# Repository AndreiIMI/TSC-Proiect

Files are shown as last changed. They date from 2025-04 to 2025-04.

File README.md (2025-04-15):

# TSC-Proiect
## Schema Bloc
SchemaBloc
## BOM (Bill of Materials)
| Component | Link | Datasheet |
|---|---|---|
| ESP32-C6-WROOM-1-N8 | [Link](https://ro.mouser.com/ProductDetail/Espressif-Systems/ESP32-C6-WROOM-1-N8?qs=8Wlm6%252BaMh8ST02Gmwp74cw%3D%3D) | [Datasheet](https://ro.mouser.com/datasheet/2/891/Espressif_ESP32_C6_WROOM_1__Datasheet_V0_1_PRELIMI-3239987.pdf) |
| 112A-TAAR-R03_ATTEND | [Link](https://www.digikey.ro/ro/products/detail/attend-technology/112A-TAAR-R03/17633923) | [Datasheet](https://www.attend.com.tw/data/download/file/112A-TAAR-R03_Spec.pdf) |
| ADAFRUIT_LEDCHIP-LED0603 | [Link](https://www.snapeda.com/parts/KP-1608SURCK/Kingbright/view-part/?ref=search&t=LED%200603) | [Datasheet](https://www.snapeda.com/parts/KP-1608SURCK/Kingbright/datasheet/) |
| ESP32_WROVER_EAGLE-LTSPICE_RR0402 | [Link](https://www.snapeda.com/parts/RC0402FR-07226RL/Yageo/view-part/) | [Datasheet](https://www.snapeda.com/parts/RC0402FR-07226RL/Yageo/datasheet/) |
| ESP32_WROVER_EAGLE-LTSPICE_CC0402 | [Link](https://componentsearchengine.com/part-view/CC0402MRX5R5BB106/YAGEO) | [Datasheet](https://componentsearchengine.com/Datasheets/2/CC0402MRX5R5BB106.pdf) |
| RCL_CPOL-EUCT3528 | [Link](https://ro.mouser.com/ProductDetail/Vishay-Sprague/TR3B106K025C1300?qs=jCGqFXxTmLdffnuDkXzk1g%3D%3D) | [Datasheet](https://www.vishay.com/docs/40080/tr3.pdf) |
| ESP32_WROVER_SPARKFUN-DISCRETESEMI_MOSFET_PCH-DMG2305UX-7 | [Link](https://ro.mouser.com/ProductDetail/Diodes-Incorporated/DMG2305UX-7?qs=L1DZKBg7t5F%2FNBHrjfxC%252Bg%3D%3D) | [Datasheet](https://www.diodes.com/assets/Datasheets/DMG2305UX.pdf) |
| 744043680IND_4828-WE-TPC_WRE | [Link](https://www.digikey.sg/en/products/detail/w%C3%BCrth-elektronik/744043680/1638515) | [Datasheet](https://www.we-online.com/components/products/datasheet/744043680.pdf) |
| BD5229G-TR | [Link](https://ro.mouser.com/ProductDetail/ROHM-Semiconductor/BD5229G-TR?qs=4kLU8WoGk0vvnhrrYwdszw%3D%3D) | [Datasheet](https://fscdn.rohm.com/en/products/databook/datasheet/ic/power/voltage_detector/bd52xxg-e.pdf) |
| ESP32_WROVER_BME680_BME680 | [Link](https://ro.mouser.com/ProductDetail/Bosch-Sensortec/BME680?qs=v271MhAjFHjo0yA%2FC4OnDQ%3D%3D) | [Datasheet](https://ro.mouser.com/datasheet/2/783/BST_BME680_DS001-1509608.pdf) |
| BUTTON_CUSTOMV1 | [Link](https://ro.mouser.com/ProductDetail/Panasonic/EVQ-P7M01P?qs=rJ%252BziJWpysz0sJAzuCybtw%3D%3D) | [Datasheet](https://industry.panasonic.com/global/en/downloads/?file_cd=402906&tab=catalog&series_cd=3457) |
| CPH3225A | [Link](https://ro.mouser.com/ProductDetail/Seiko-Semiconductors/CPH3225A?qs=3etwrb1wR%252BhUOph6lAO7eg%3D%3D) | [Datasheet](https://ro.mouser.com/datasheet/2/360/Seiko_Instruments_MicroBattery_E_20230330_2024Jan_-3561061.pdf) |
| DS3231SN# | [Link](https://ro.mouser.com/ProductDetail/Analog-Devices-Maxim-Integrated/DS3231SN?qs=1eQvB6Dk1vhUlr8%2FOrV0Fw%3D%3D) | [Datasheet](https://ro.mouser.com/datasheet/2/609/DS3231-3421123.pdf) |
| ESP32C6_VARISTORCN1812 | [Link](https://eu.mouser.com/ProductDetail/KEMET/VC1812L501R008?qs=jj7GbYRQuOa1j1%2F3gPpdvQ%3D%3D) | [Datasheet](https://eu.mouser.com/datasheet/2/447/KEM_V0002_VC-3316862.pdf) |
| ESP32_WROVER_AVX---SD0805S020S1R0_AVX_SD0805S020S1R0_0_0AVX_SD0805S020S1R0_0_0 | [Link](https://eu.mouser.com/ProductDetail/KYOCERA-AVX/SD0805S020S1R0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) | [Datasheet](https://eu.mouser.com/datasheet/2/40/schottky-3165252.pdf) |
| FH34SRJ-24S-0.5SH_99_ | [Link](https://eu.mouser.com/ProductDetail/Hirose-Connector/FH34SRJ-24S-05SH99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) | [Datasheet](https://eu.mouser.com/datasheet/2/185/FH34SRJ_24S_0_5SH_99__CL0580_1255_6_99_2DDrawing_0-1615044.pdf) |
| MAX17048G+T10 | [Link](https://eu.mouser.com/ProductDetail/Analog-Devices-Maxim-Integrated/MAX17048G+T10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) | [Datasheet](https://eu.mouser.com/datasheet/2/609/MAX17048_MAX17049-3469099.pdf) |
| MBR0530 | [Link](https://eu.mouser.com/ProductDetail/Micro-Commercial-Components-MCC/MBR0530-TP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) | [Datasheet](https://eu.mouser.com/datasheet/2/258/MBR0520_MBR0580_SOD123_-2492194.pdf) |
| ESP32_WROVER_SPARKFUN-IC-POWER_MCP73831 | [Link](https://ro.mouser.com/ProductDetail/Microchip-Technology/MCP73831-2DCI-MC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) | [Datasheet](https://ro.mouser.com/datasheet/2/268/MCP73831_Family_Data_Sheet_DS20001984H-3441711.pdf) |
| PGB1010603MR | [Link](https://ro.mouser.com/ProductDetail/Littelfuse/PGB1010603MR?qs=gu7KAQ731URLg4GSnNNN7Q%3D%3D) | [Datasheet](https://www.littelfuse.com/assetdocs/pulseguard-esd-suppressors-pgb1-datasheet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) |
| QWIIC_CONNECTORJS-1MM | [Link](https://www.sparkfun.com/qwiic-jst-connector-smd-4-pin-vertical.html) | [Datasheet](https://www.jst-mfg.com/product/pdf/eng/eSH.pdf?5ec58813d214e) |
| SAMACSYS_PARTS_USB4110-GF-A | [Link](https://eu.mouser.com/ProductDetail/GCT/USB4110-GF-A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) | [Datasheet](https://eu.mouser.com/datasheet/2/837/GCT_USB4110_Product_Drawing___20k_cycles-3455479.pdf) |
| SI1308EDL-T1-GE3 | [Link](https://eu.mouser.com/ProductDetail/Vishay-Semiconductors/SI1308EDL-T1-GE3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) | [Datasheet](https://www.vishay.com/docs/63399/si1308edl.pdf) |
| USBLC6-2SC6Y | [Link](https://eu.mouser.com/ProductDetail/STMicroelectronics/USBLC6-2SC6Y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) | [Datasheet](https://eu.mouser.com/datasheet/2/389/usblc6_2sc6y-1852505.pdf) |
| SJ | [Link](https://grabcad.com/library/solder-jumpers-1) | [Datasheet](https://github.com/cristiandeda/TSC_E-BookReader/blob/main) |
| W25Q512JVEIQ | [Link](https://eu.mouser.com/ProductDetail/Winbond/W25Q512JVEIQ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) | [Datasheet](https://eu.mouser.com/datasheet/2/949/Winbond_W25Q512JV_Datasheet-3240039.pdf) |
| XC6220A331MR-G | [Link](https://eu.mouser.com/ProductDetail/Torex-Semiconductor/XC6220A331MR-G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) | [Datasheet](https://eu.mouser.com/datasheet/2/760/xc6220-3371556.pdf) |
## Descrierea funcționalității hardware
Această placă integrează multiple componente pentru a oferi o soluție completă de control, senzorizare și afișare cu consum redus, ideală pentru aplicații IoT.

### Alimentare și Încărcare
* #### Conector USB-C
  Oferă atât alimentare principală (5V), cât și comunicație de date.

* #### Regulator tensiune (IC1)
  Convertor step-down care aduce tensiunea de la 5V la 3.3V, necesară pentru alimentarea ESP32 și a celorlalte circuite logice.

* #### Protecție la supratensiuni (TVS - D1, PFMF.050.1)
  Diodă TVS care protejează linia de alimentare USB și comunicație împotriva descărcărilor electrostatice (ESD) și supratensiunilor.

* #### Control încărcare baterie (MCP73831)
  Circuit dedicat pentru încărcarea bateriilor Li-Po, cu protecție la supraîncărcare și descărcare. Condensatorii C1 și C2 filtrează zgomotul de pe linia de alimentare.

* #### Monitorizare baterie (MAX17048)
  Cititor de nivel al bateriei cu comunicație I2C, oferă date precise despre starea acumulatorului în timp real.

### Memorie și Stocare
* #### Memorie NOR Flash SPI (W25Q512JVEIQ)
  Stocare de 64MB pentru fișiere (imagini, texte, baze de date), conectată la ESP32 prin SPI.

* #### Cititor card SD
  Conectat pe interfață SPI (IO8–IO11), permite extinderea capacității de stocare, ideal pentru loguri sau import de fișiere externe.

### Control Principal - ESP32-C6
* #### Microcontroller ESP32-C6-WROOM-1-N8
  Nucleul principal al plăcii, gestionează toate perifericele. Suportă Wi-Fi 6, BLE 5.2, Zigbee și Thread. Dispune de GPIO-uri versatile pentru SPI, I2C, UART și control direct pentru afișajele e-paper.

### Ceas în Timp Real (RTC)
* #### DS3231SN
  Modul de ceas cu precizie ridicată, conectat prin I2C. Are o baterie de rezervă ce menține ora actualizată chiar și fără alimentare principală.

### Senzor Ambiental
* #### BME688
  Senzor avansat care măsoară temperatura, umiditatea, presiunea atmosferică și calitatea aerului. Comunicarea se face prin I2C.

### Afișaj E-Paper
* #### Header dedicat pentru E-Ink Display
  Permite conectarea unui afișaj e-paper cu consum ultra-redus.

* #### Circuit de control semnal (MBR0530, L1, Q3)
  Asigură comutarea corectă a tensiunii și semnalelor pentru afișaj.

* #### Selectare ecran
  Prin jumperul S1 se poate selecta tipul de e-paper utilizat.

### Interfețe Extinse
* #### Qwiic / Stemma QT
  Conector standard JST-SH cu 4 pini pentru adăugarea de senzori sau module I2C externe cu plug-and-play.

* #### Test Pads GPIO
  Paduri expuse pentru pini importanți ai ESP32. Ușurează depanarea, măsurătorile sau conectarea de periferice suplimentare.

### Protecție și Control
* #### Protecție ESD pe SPI & Qwiic
  Include diode TVS și rezistențe pentru protecția semnalelor împotriva descărcărilor electrostatice.

* #### Butoane de control (RESET & BOOT)
  RESET – repornește sistemul; BOOT – folosit pentru programarea ESP32. Ambele conectate la pini esențiali (EN și IO0).

## Descrierea Pinilor ESP32-C6

| **Pin ESP32-C6** | **Nume Semnal** | **Componentă Asociată** | **Scop / Funcție** |
|---|---|---|---|
| **GND** | GND | Toate componentele | Masă comună pentru alimentare și semnal. |
| **EN** | Enable | Buton Reset | Resetează microcontrollerul la apăsare. |
| **IO0** | GPIO0 | Buton BOOT | Intrare în modul de boot la apăsare. |

### Test & GPIO General

| **Pin ESP32-C6** | **Nume Semnal** | **Componentă Asociată** | **Scop / Funcție** |
|---|---|---|---|
| **IO1** | GPIO1 | Test Pad TP11 | I/O general sau pentru debug. |
| **IO2** | GPIO2 | Test Pad TP12 | I/O general sau pentru debug. |
| **IO3** | GPIO3 | Test Pad TP13 | I/O general sau pentru debug. |

### Memorie NOR Flash (SPI)

| **Pin ESP32-C6** | **Nume Semnal** | **Componentă Asociată** | **Scop / Funcție** |
|---|---|---|---|
| **IO4** | CS | SPI Flash (W25Q512JVEIQ) | Chip Select pentru memoria externă. |
| **IO5** | CLK | SPI Flash | Clock SPI pentru NOR Flash. |
| **IO6** | MISO | SPI Flash | Date din NOR Flash către ESP32. |
| **IO7** | MOSI | SPI Flash | Date de la ESP32 către NOR Flash. |

### Card SD (SPI)

| **Pin ESP32-C6** | **Nume Semnal** | **Componentă Asociată** | **Scop / Funcție** |
|---|---|---|---|
| **IO8** | CS | SD Card | Chip Select pentru card SD. |
| **IO9** | CLK | SD Card | Clock SPI pentru card SD. |
| **IO10** | MISO | SD Card | Date de pe card SD către ESP32. |
| **IO11** | MOSI | SD Card | Date de la ESP32 către card SD. |

### E-Paper Display

| **Pin ESP32-C6** | **Nume Semnal** | **Componentă Asociată** | **Scop / Funcție** |
|---|---|---|---|
| **IO12** | BUSY / RST / etc. | E-Paper Header | Semnale de control pentru afișaj. |
| **IO13** | - | E-Paper Header | Semnal suplimentar pentru afișaj. |
| **IO14** | - | E-Paper Header | Semnal suplimentar pentru afișaj. |
| **IO15** | - | E-Paper Header | Semnal suplimentar pentru afișaj. |

### Magistrală I2C (RTC & Senzor Mediu)

| **Pin ESP32-C6** | **Nume Semnal** | **Componentă Asociată** | **Scop / Funcție** |
|---|---|---|---|
| **IO16** | SCL | RTC (DS3231), BME688 | Clock pentru comunicația I2C. |
| **IO17** | SDA | RTC (DS3231), BME688 | Date pentru comunicația I2C. |

### Serial Debug / Qwiic

| **Pin ESP32-C6** | **Nume Semnal** | **Componentă Asociată** | **Scop / Funcție** |
|---|---|---|---|
| **IO18** | UART_RX | Qwiic / Debug Header | Recepție serială (ex: debugging, interfață Qwiic). |
| **IO19** | UART_TX | Qwiic / Debug Header | Transmisie serială. |

## Pași de Implementare

1. **Proiectarea Schemei**
   - Am realizat schema electrică folosind componente din biblioteca specificată.
   - Am verificat schema cu ERC și am rezolvat toate erorile relevante.
   - M-am asigurat că toate componentele au footprint corect și conexiuni valide.

2. **Plasarea Componentelor pe PCB**
   - Am plasat toate componentele exclusiv pe layer-ul **TOP**, conform cerințelor.
   - Am amplasat corect condensatoarele de decuplare (100nF) lângă pinii de alimentare.
   - Am poziționat antena modulului ESP32 spre exteriorul plăcii și am decupat zona de sub ea.
   - Am ignorat erorile de dimension generate de butoane și mufa USB, conform instrucțiunilor.

3. **Rutarea PCB-ului**
   - Am rutat traseele de alimentare cu **width = 0.3mm** și cele de semnal cu **minim 0.15mm**.
   - Am evitat unghiurile drepte și am minimizat utilizarea de vias-uri pe traseele de putere.
   - Fiind o placă dublu strat, am aplicat **via stitching** între planurile de masă.
   - Nu am rutat trasee sub antena ESP32 și am decupat zona PCB-ului din acea regiune.

4. **Verificare și Validare**
   - Am folosit fișierul de verificare pentru DRC și am corectat toate problemele importante.
   - Am ignorat eroarea “Only INPUT pins on NET ID” conform indicațiilor.
   - Am marcat clar toate test pad-urile în silkscreen cu denumirile semnalelor (ex. MOSI, RX).

5. **Realizarea Silkscreen-ului**
   - Am păstrat silkscreen-ul clar și lizibil, cu **numele componentelor**, fără valorile acestora.

6. **Modelarea 3D**
   - Am importat modelul 3D al PCB-ului în carcasa furnizată.
   - Am desenat bateria și ecranul conform dimensiunilor mecanice din datasheet-uri.

7. **Generarea Fișierelor Finale**
   - Am generat fișierele **Gerber** conform tutorialului oferit.
   - Am creat fișierele **BOM** și **Pick and Place** pentru fabricație, urmând pașii din tutorial.
   - Pentru componente și modele 3D, am folosit [Component Search Engine](https://componentsearchengine.com).

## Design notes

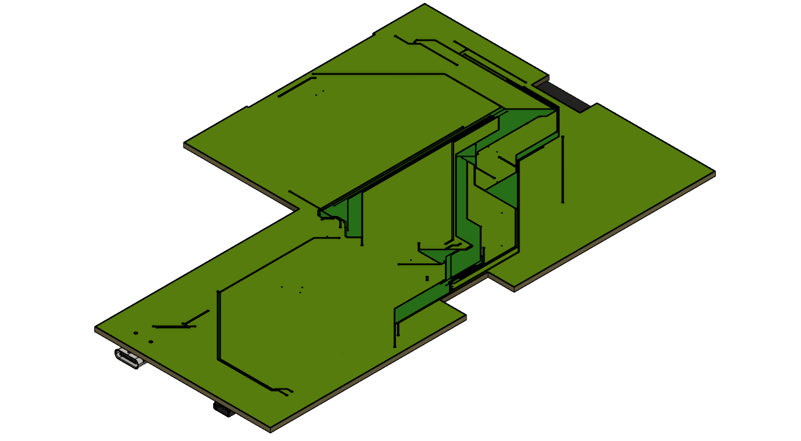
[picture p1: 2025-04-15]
Images/PCB Bottom.png

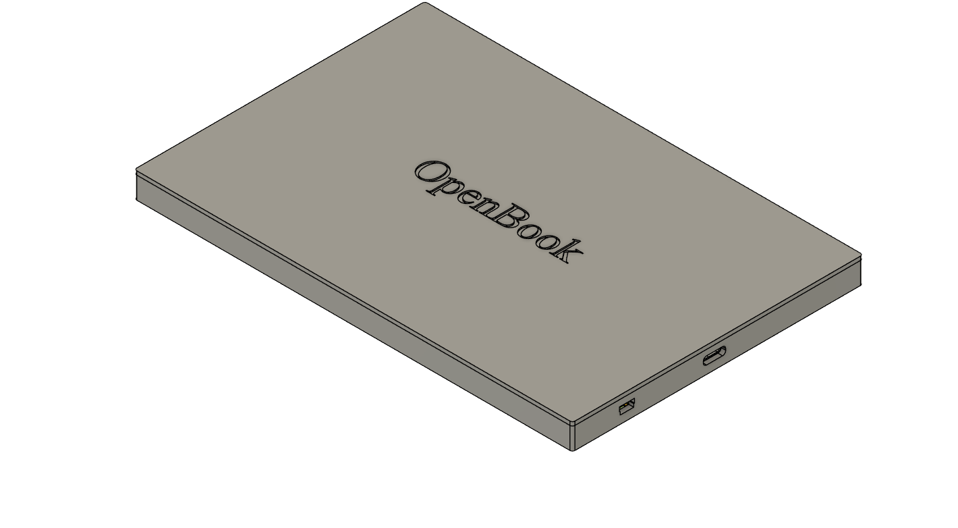
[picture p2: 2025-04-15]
Images/OpenBook_Model-Full v2.png

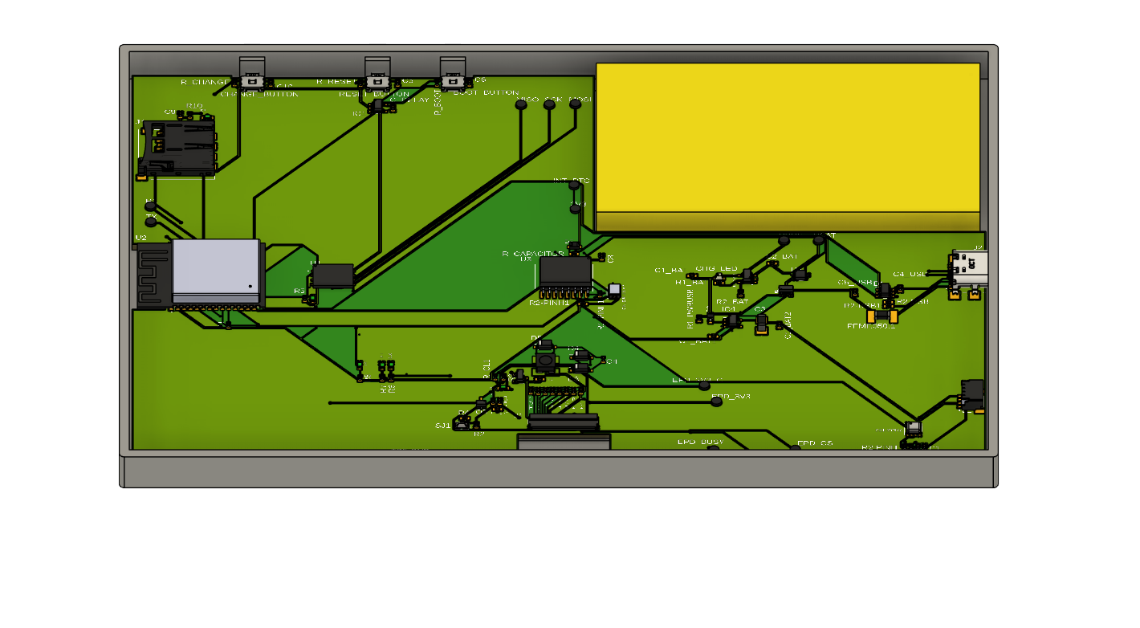
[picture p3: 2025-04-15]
Images/OpenBook_Model-Full Open.png

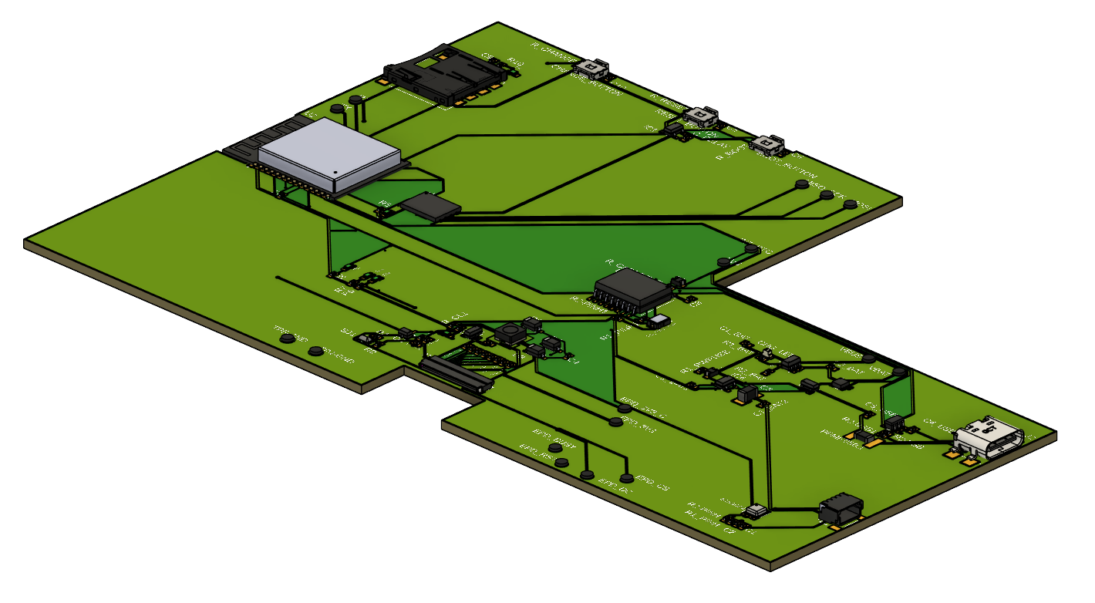
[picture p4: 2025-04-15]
Images/PCB.png

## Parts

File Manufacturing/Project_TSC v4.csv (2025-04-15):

Qty | Value | Device | Package | Parts | Description | ARROW_PART_NUMBER | ARROW_PRICE-STOCK | AVAILABILITY | CENTROID_NOT_SPECIFIED | CHECK_PRICES | COPYRIGHT | DATASHEET | DESCRIPTION | DIGIKEY_DESCRIPTION | DIGIKEY_PART_NUMBER | HEIGHT | LEAD_FREE | MANUFACTURER_NAME | MANUFACTURER_PART_NUMBER | MF | MFR_NAME | MOUSER_PART_NUMBER | MOUSER_PRICE-STOCK | MOUSER_TESTING_PART_NUMBER | MOUSER_TESTING_PRICE-STOCK | MP | MPN | PACKAGE | POPULARITY | PREFIX | PRICE | PROD_ID | PURCHASE-URL | ROHS | SNAPEDA_LINK | SPICEMODEL | SPICEPREFIX | TEMPERATURE_RANGE_HIGH | TEMPERATURE_RANGE_LOW | TP_SIGNAL_NAME | VALUE
1 |  | ADAFRUIT_LEDCHIP-LED0603 | ADAFRUIT_CHIP-LED0603 | CHG_LED | LED
1 |  | SJ | SJ | SJ1 | SMD solder JUMPER |  |  |  |  |  |  |  |  |  |  |  |  |  |  |  |  |  |  |  |  |  |  |  | 3
1 | 0.47 | ESP32_WROVER_EAGLE-LTSPICE_RR0402 | ESP32_WROVER_EAGLE-LTSPICE_R0402 | R3 | RESISTOR, European symbol |  |  |  |  |  |  |  |  |  |  |  |  |  |  |  |  |  |  |  |  |  |  |  |  |  |  |  |  |  |  | NONE | R
1 | 100K | ESP32_WROVER_EAGLE-LTSPICE_RR0402 | ESP32_WROVER_EAGLE-LTSPICE_R0402 | R1_PWRUSB | RESISTOR, European symbol |  |  |  |  |  |  |  |  |  |  |  |  |  |  |  |  |  |  |  |  |  |  |  |  |  |  |  |  |  |  | NONE | R
8 | 100nF | EAGLE-LTSPICE_CC0402 | EAGLE-LTSPICE_C0402 | C1, C2, C4_USB, C6, C8, C9, C10, C_DELAY | CAPACITOR, European symbol |  |  |  |  |  |  |  |  |  |  |  |  |  |  |  |  |  |  |  |  |  |  |  |  |  |  |  |  |  |  | NONE | C
1 | 100uF TANT | RCL_CPOL-EUCT3528 | RCL_CT3528 | C3 | POLARIZED CAPACITOR, European symbol |  |  |  |  |  |  |  |  |  |  |  |  |  |  |  |  |  |  |  |  |  |  |  | 0 |  |  |  |  |  |  |  | C
16 | 10K | ESP32_WROVER_EAGLE-LTSPICE_RR0402 | ESP32_WROVER_EAGLE-LTSPICE_R0402 | R1, R1_PINH, R1_PINH1, R2-PINH, R2-PINH1, R4, R5, R6, R7, R8, R9, R10, R_BOOT, R_CHANGE, R_CL1, R_RESET | RESISTOR, European symbol |  |  |  |  |  |  |  |  |  |  |  |  |  |  |  |  |  |  |  |  |  |  |  |  |  |  |  |  |  |  | NONE | R
1 | 10uF | EAGLE-LTSPICE_CC0402 | EAGLE-LTSPICE_C0402 | C7 | CAPACITOR, European symbol |  |  |  |  |  |  |  |  |  |  |  |  |  |  |  |  |  |  |  |  |  |  |  |  |  |  |  |  |  |  | NONE | C
1 | 112A-TAAR-R03_ATTEND | 112A-TAAR-R03_ATTEND | 112ATAARR03ATTEND | J4 | Micro SD Card Socket, Push-Push Type, Top Mount, SMT, H=1.83mm, 10u |  |  |  |  |  |  |  | Micro SD Card Socket | Push-Push Type | Top Mount | SMT | H=1.83mm | 10u |  |  | 1.9mm |  | ATTEND | 112A-TAAR-R03 ATTEND
1 | 15 | ESP32_WROVER_EAGLE-LTSPICE_RR0402 | ESP32_WROVER_EAGLE-LTSPICE_R0402 | R_CAPACITOR | RESISTOR, European symbol |  |  |  |  |  |  |  |  |  |  |  |  |  |  |  |  |  |  |  |  |  |  |  |  |  |  |  |  |  |  | NONE | R
1 | 1uF | EAGLE-LTSPICE_CC0402 | EAGLE-LTSPICE_C0402 | C5 | CAPACITOR, European symbol |  |  |  |  |  |  |  |  |  |  |  |  |  |  |  |  |  |  |  |  |  |  |  |  |  |  |  |  |  |  | NONE | C
10 | 1uF/50V | EAGLE-LTSPICE_CC0402 | EAGLE-LTSPICE_C0402 | EPD_C1, EPD_C2, EPD_C5, EPD_C6, EPD_C7, EPD_C8, EPD_C9, EPD_C10, EPD_C11, EPD_C12 | CAPACITOR, European symbol |  |  |  |  |  |  |  |  |  |  |  |  |  |  |  |  |  |  |  |  |  |  |  |  |  |  |  |  |  |  | NONE | C
1 | 2.2 | ESP32_WROVER_EAGLE-LTSPICE_RR0402 | ESP32_WROVER_EAGLE-LTSPICE_R0402 | R2 | RESISTOR, European symbol |  |  |  |  |  |  |  |  |  |  |  |  |  |  |  |  |  |  |  |  |  |  |  |  |  |  |  |  |  |  | NONE | R
1 | 200 | ESP32_WROVER_EAGLE-LTSPICE_RR0402 | ESP32_WROVER_EAGLE-LTSPICE_R0402 | R1_BAT | RESISTOR, European symbol |  |  |  |  |  |  |  |  |  |  |  |  |  |  |  |  |  |  |  |  |  |  |  |  |  |  |  |  |  |  | NONE | R
2 | 20V/4.2A/52mO/1.4W | ESP32_WROVER_SPARKFUN-DISCRETESEMI_MOSFET_PCH-DMG2305UX-7 | ESP32_WROVER_SPARKFUN-DISCRETESEMI_SOT23-3 | Q1, Q2 | P-channel MOSFETs |  |  |  |  |  |  |  |  |  |  |  |  |  |  |  |  |  |  |  |  |  |  |  |  |  |  | TRAN-14388 |  |  |  |  |  |  |  |  | 20V/4.2A/52mO/1.4W
1 | 2K | ESP32_WROVER_EAGLE-LTSPICE_RR0402 | ESP32_WROVER_EAGLE-LTSPICE_R0402 | R2_BAT | RESISTOR, European symbol |  |  |  |  |  |  |  |  |  |  |  |  |  |  |  |  |  |  |  |  |  |  |  |  |  |  |  |  |  |  | NONE | R
5 | 4.7uF | EAGLE-LTSPICE_CC0402 | EAGLE-LTSPICE_C0402 | C1_BAT, C1_BAT1, C1_BAT2, C2_BAT, C5_USB | CAPACITOR, European symbol |  |  |  |  |  |  |  |  |  |  |  |  |  |  |  |  |  |  |  |  |  |  |  |  |  |  |  |  |  |  | NONE | C
1 | 4.7uF/25V | EAGLE-LTSPICE_CC0402 | EAGLE-LTSPICE_C0402 | C4 | CAPACITOR, European symbol |  |  |  |  |  |  |  |  |  |  |  |  |  |  |  |  |  |  |  |  |  |  |  |  |  |  |  |  |  |  | NONE | C
2 | 5k1 | ESP32_WROVER_EAGLE-LTSPICE_RR0402 | ESP32_WROVER_EAGLE-LTSPICE_R0402 | R2-USB, R2-USB1 | RESISTOR, European symbol |  |  |  |  |  |  |  |  |  |  |  |  |  |  |  |  |  |  |  |  |  |  |  |  |  |  |  |  |  |  | NONE | R
1 | 68uH | 744043680IND_4828-WE-TPC_WRE | IND_4828-WE-TPC_WRE | L1 |  |  |  |  |  |  | Copyright (C) 2024 Ultra Librarian. All rights reserved. |  |  |  |  |  |  |  | 744043680 |  | Wurth Electronics
1 | BD5229G-TR | BD5229G-TR | SOT95P280X120-5N | IC1 | Voltage Detector with Adjustable Delay Time: CMOS processes are utilized to develop high precision, low current consumption CMOS reset ICs that allow arbitrary setting of the delay time. The extensive lineup includes both Nch Open Drain and CMOS output types in a wide range of detection voltages (from 2.3V to 6.0V, in 0.1V steps), enabling selection of the ideal solution based on customer requirements. In addition, the entire series is of course both lead-free and RoHS-compliant. |  |  |  |  |  |  |  | Voltage Detector with Adjustable Delay Time: CMOS processes are utilized to develop high precision | low current consumption CMOS reset ICs that allow arbitrary setting of the delay time. The extensive lineup includes both Nch Open Drain and CMOS output types in a wide range of detection voltages (from 2.3V to 6.0V | in 0.1V steps) | enabling selection of the ideal solution based on customer requirements. In addition | the entire series is of course both lead-free and RoHS-compliant. |  |  | 1.25mm |  | ROHM Semiconductor | BD5229G-TR |  |  | 755-BD5229G-TR | https://www.mouser.co.uk/ProductDetail/ROHM-Semiconductor/BD5229G-TR?qs=4kLU8WoGk0vvnhrrYwdszw%3D%3D
1 | BME680 | ESP32_WROVER_BME680_BME680 | ESP32_WROVER_BME680_PSON80P300X300X100-8N | SENSOR2 | Integrated Environmental Unit |  |  | Unavailable |  |  |  |  | Integrated Environmental Unit |  |  |  |  |  |  | Bosch Sensortec |  |  |  |  |  | BME680 |  | LGA-8 Bosch Tools |  |  | None
1 | BOOT_BUTTON | BUTTON_CUSYOMV1 | MYBUTTON | BOOT_BUTTON
1 | CHANGE_BUTTON | BUTTON_CUSYOMV1 | MYBUTTON | CHANGE_BUTTON
1 | CPH3225A | CPH3225A | CAPCP3225X100N | C10_SUPERCAP | Cap 0.011F 3.3V 1210 Flat Check availability |  |  | Not in stock |  | https://www.snapeda.com/parts/CPH3225A/Seiko+Instruments/view-part/?ref=eda |  |  | 11 mF (EDLC) Supercapacitor 3.3 V 1210 (3225 Metric) - - |  |  |  |  |  |  | Seiko Instruments |  |  |  |  |  | CPH3225A |  | 1210 Seiko |  |  | None |  | https://www.snapeda.com/api/url_track_click_mouser/?unipart_id=562593&manufacturer=Seiko Instruments&part_name=CPH3225A&search_term=None |  | https://www.snapeda.com/parts/CPH3225A/Seiko+Instruments/view-part/?ref=snap
1 | DS3231SN# | DS3231SN# | SOIC127P1032X265-16N | U3 | Real Time Clock Serial 16-Pin SOIC W T/R Check availability |  |  | In Stock |  | https://www.snapeda.com/parts/DS3231SN%23/Analog+Devices/view-part/?ref=eda |  |  | Extremely Accurate I²C-Integrated RTC/TCXO/Crystal |  |  |  |  |  |  | Analog Devices |  |  |  |  |  | DS3231SN# |  | SOIC-16 Maxim |  |  | None |  | https://www.snapeda.com/api/url_track_click_mouser/?unipart_id=99048&manufacturer=Analog Devices&part_name=DS3231SN#&search_term=None |  | https://www.snapeda.com/parts/DS3231SN%23/Analog+Devices/view-part/?ref=snap
1 | ESP32-C6-WROOM-1-N8 | ESP32-C6-WROOM-1-N8 | XCVR_ESP32-C6-WROOM-1-N8 | U2 | Check availability |  |  | In Stock |  | https://www.snapeda.com/parts/ESP32-C6-WROOM-1-N8/Espressif+Systems/view-part/?ref=eda |  |  | Multiprotocol Modules ESP32-C6 module | Wi-Fi 6 in 2.4 GHz band | Bluetooth 5 | Zigbee 3.0 and Thread. ESP34-WROOM Compatible - ENGINEERING SAMPLE |  |  |  |  |  |  | Espressif Systems |  |  |  |  |  | ESP32-C6-WROOM-1-N8 |  | None |  |  | None |  |  |  | https://www.snapeda.com/parts/ESP32-C6-WROOM-1-N8/Espressif+Systems/view-part/?ref=snap
1 | ESP32C6_VARISTORCN1812 | ESP32C6_VARISTORCN1812 | ESP32C6_VARISTOR_CT/CN1812 | PFMF.050.1 | VARISTOR |  |  |  |  |  |  |  |  |  |  |  |  |  |  |  |  |  |  |  |  |  |  |  | 0
2 | ESP32_WROVER_AVX---SD0805S020S1R0_AVX_SD0805S020S1R0_0_0AVX_SD0805S020S1R0_0_0 | ESP32_WROVER_AVX---SD0805S020S1R0_AVX_SD0805S020S1R0_0_0AVX_SD0805S020S1R0_0_0 | ESP32_WROVER_AVX---SD0805S020S1R0_AVX_SD0805S020S1R0_0 | D2, D7 | Schottky Barrier Rectifier Diode |  |  |  | No |  |  | http://datasheets.avx.com/schottky.pdf |  | DIODE SCHOTTKY 20V 1A 0805 | 478-7800-1-ND |  | yes |  |  | AVX |  | 581-SD0805S020S1R0 |  |  |  |  |  | 0805 (2012 metric) |  | D |  |  |  | yes |  |  |  | +125°C | -55°C
1 | ESP32_WROVER_SPARKFUN-IC-POWER_MCP73831 | ESP32_WROVER_SPARKFUN-IC-POWER_MCP73831 | ESP32_WROVER_SPARKFUN-IC-POWER_SOT23-5 | MCP73831 | MCP73831T Li-Ion, Li-Pol Controller |  |  |  |  |  |  |  |  |  |  |  |  |  |  |  |  |  |  |  |  |  |  |  |  |  |  | IC-09995
1 | FH34SRJ-24S-0.5SH_99_ | FH34SRJ-24S-0.5SH_99_ | FH34SRJ24S05SH99 | J1 | (0.50mm) Surface Mount, Right Angle |  |  |  |  |  |  |  | 24 Position FFC | FPC Connector Contacts | (0.50mm) Surface Mount | Right Angle |  |  | 1.1mm |  | Hirose | FH34SRJ-24S-0.5SH(99) |  |  | 798-FH34SRJ24S05SH99 | https://www.mouser.co.uk/ProductDetail/Hirose-Connector/FH34SRJ-24S-0.5SH99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
1 | GND | TPTP20R | TP20R | TP5-GND | Test pad |  |  |  |  |  |  |  |  |  |  |  |  |  |  |  |  |  |  |  |  |  |  |  | 2
1 | MAX17048G+T10 | MAX17048G+T10 | SON50P200X200X80-9N | U4 | Check availability |  |  | In Stock |  | https://www.snapeda.com/parts/MAX17048G+T10/Analog+Devices/view-part/?ref=eda |  |  | 3µA 1-Cell/2-Cell Fuel Gauge with ModelGauge |  |  |  |  |  |  | Analog Devices |  |  |  |  |  | MAX17048G+T10 |  | TDFN-8 Maxim |  |  | None |  | https://www.snapeda.com/api/url_track_click_mouser/?unipart_id=329239&manufacturer=Analog Devices&part_name=MAX17048G+T10&search_term=None |  | https://www.snapeda.com/parts/MAX17048G+T10/Analog+Devices/view-part/?ref=snap
3 | MBR0530 | MBR0530 | SOD3716X135N | D3, D4, D5 | ON SEMICONDUCTOR - MBR0530 - DIODE, SCHOTTKY, 0.5A, 30V, SOD-123 |  |  | In Stock |  | https://www.snapeda.com/parts/MBR0530/Onsemi/view-part/?ref=eda |  |  | Diode Schottky 30 V 500mA Surface Mount SOD-123 |  |  |  |  |  |  | ON Semiconductor |  |  |  |  |  | MBR0530 |  | SOD-123-2 ON Semiconductor |  |  | None |  | https://www.snapeda.com/api/url_track_click_mouser/?unipart_id=179458&manufacturer=ON Semiconductor&part_name=MBR0530&search_term=None |  | https://www.snapeda.com/parts/MBR0530/Onsemi/view-part/?ref=snap
6 | PGB1010603MR | PGB1010603MR | DIOC1608X36N | D6, D8, D9, D10, D11, D12 | Check availability |  |  | In Stock |  | https://www.snapeda.com/parts/PGB1010603MR/Littelfuse/view-part/?ref=eda |  |  | 150V (Typ) Clamp - Ipp Tvs Diode Surface Mount 0603 (1608 Metric) |  |  |  |  |  |  | Littelfuse Inc. |  |  |  |  |  | PGB1010603MR |  | 0603 Littelfuse Inc. |  |  | None |  | https://www.snapeda.com/api/url_track_click_mouser/?unipart_id=5659453&manufacturer=Littelfuse Inc.&part_name=PGB1010603MR&search_term=None |  | https://www.snapeda.com/parts/PGB1010603MR/Littelfuse/view-part/?ref=snap
1 | QWIIC_RIGHT_ANGLE | QWIIC_CONNECTORJS-1MM | JST04_1MM_RA | J3 | SparkFun I2C Standard Qwiic Connector |  |  |  |  |  |  |  |  |  |  |  |  |  |  |  |  |  |  |  |  |  |  |  |  |  |  | CONN-13694 |  |  |  |  |  |  |  |  | QWIIC_RIGHT_ANGLE
1 | RESET BUTTON | BUTTON_CUSYOMV1 | MYBUTTON | RESET_BUTTON
1 | SAMACSYS_PARTS_USB4110-GF-A | SAMACSYS_PARTS_USB4110-GF-A | SAMACSYS_PARTS_USB4110GFA | J2 | CONN USB 2.0 TYPE-C R/A SMT |  |  |  |  |  |  |  | CONN USB 2.0 TYPE-C R/A SMT |  |  | 3.26mm |  | GCT (GLOBAL CONNECTOR TECHNOLOGY) | USB4110-GF-A |  |  | 640-USB4110-GF-A | https://www.mouser.co.uk/ProductDetail/GCT/USB4110-GF-A?qs=KUoIvG%2F9IlYiZvIXQjyJeA%3D%3D
1 | SI1308EDL-T1-GE3 | SI1308EDL-T1-GE3 | SOT65P210X110-3N | Q3 | MOSFET N-Ch 30V 1.5A TrenchFET SC70 Vishay Si1308EDL-T1-GE3 N-channel MOSFET Transistor, 1.5 A, 30 V, 3-Pin SC-70 |  |  | In Stock |  | https://www.snapeda.com/parts/SI1308EDL-T1-GE3/Vishay+Siliconix/view-part/?ref=eda |  |  | Si1308EDL-T1-GE3 N-channel MOSFET Transistor | 1.5 A | 30 V | 3-Pin SC-70 | Siliconix / Vishay SI1308EDL-T1-GE3 |  |  |  |  |  |  | Vishay Siliconix |  |  |  |  |  | SI1308EDL-T1-GE3 |  | SOT-323 Vishay Semiconductor |  |  | None |  | https://www.snapeda.com/api/url_track_click_mouser/?unipart_id=274603&manufacturer=Vishay Siliconix&part_name=SI1308EDL-T1-GE3&search_term=None |  | https://www.snapeda.com/parts/SI1308EDL-T1-GE3/Vishay+Siliconix/view-part/?ref=snap
16 | TPTP20R | TPTP20R | TP20R | 3V3, EPD_3V3, EPD_3V3_C, EPD_BUSY, EPD_CS, EPD_DC, EPD_RST, INT_RTC, MISO, MOSI, RX, SCK, TP4-GND, TX, VBAT, VBUS | Test pad |  |  |  |  |  |  |  |  |  |  |  |  |  |  |  |  |  |  |  |  |  |  |  | 2
1 | USBLC6-2SC6Y | USBLC6-2SC6Y | SOT95P280X145-6N | D1 | Low Cap. ESD Protection Auto SOT-23-6 STMicroelectronics USBLC6-2SC6Y, Dual Uni-Directional TVS Diode Array, 6-Pin SOT-23 |  |  | In Stock |  | https://www.snapeda.com/parts/USBLC6-2SC6Y/STMicroelectronics/view-part/?ref=eda |  |  | 17V Clamp 5A (8/20µs) Ipp Tvs Diode Surface Mount SOT-23-6 |  |  |  |  |  |  | STMicroelectronics |  |  |  |  |  | USBLC6-2SC6Y |  | SOT-23-6 STMicroelectronics |  |  | None |  |  |  | https://www.snapeda.com/parts/USBLC6-2SC6Y/STMicroelectronics/view-part/?ref=snap
1 | W25Q512JVEIQ | W25Q512JVEIQ | SON127P600X800X80-9N | U1 | Check availability |  |  | In Stock |  | https://www.snapeda.com/parts/W25Q512JVEIQ/Winbond+Electronics/view-part/?ref=eda |  |  | FLASH - NOR Memory IC 512Mb (64M x 8) SPI - Quad I/O 133 MHz 8-WSON (8x6) |  |  |  |  |  |  | Winbond Electronics |  |  |  |  |  | W25Q512JVEIQ |  | Package |  |  | None |  |  |  | https://www.snapeda.com/parts/W25Q512JVEIQ/Winbond+Electronics/view-part/?ref=snap
1 | XC6220A331MR-G | XC6220A331MR-G | SOT95P280X120-5N | IC4 | LDO Voltage Regulators |  |  |  |  |  |  |  | LDO Voltage Regulators |  |  | 1.2mm |  | Torex | XC6220A331MR-G |  |  | 865-XC6220A331MR-G | https://www.mouser.co.uk/ProductDetail/Torex-Semiconductor/XC6220A331MR-G?qs=AsjdqWjXhJ8ZSWznL1J0gg%3D%3D

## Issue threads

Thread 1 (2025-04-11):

Schematic

SebiBahrin, 2025-04-11:
1.In cadrul Schematic-ului, ai 2 warning-uri care pot fi rezolvate extrem de usor:
Net PREVGH si net GND Overlaps pin. Trebuie doar sa muti net-ul verde putin mai la stanga astfel incat sa nu mai aiba contact cu pinii rosii.

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

2.De asemenea, in cadrul Test Pads ai mici greseli de scriere, EDP in loc de EPD cum era corect. Asta iti genereaza si probleme. Dupa ce modifici aici typo-urile, nu uita sa schimbi si denumirea test pad-urilor pentru a fi aceeasi cu tag-urile lor

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

Closed 2025-04-15.

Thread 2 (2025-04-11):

README

SebiBahrin, 2025-04-11:
Readme-ul incarcat de tine nu respecta complet modelul sugerat. Pentru a fi corect, asigura-te ca bifezi **TOATE** cerintele de mai jos:
O diagramă bloc cu toate componentele proiectului vostru și cum sunt ele legate .
Un BOM (Bill Of Materials) sub formă de tabel cu componentele sau modulele pe care le-ați folosit și link-uri către locul de unde le puteți procura și link către datasheet-ul lor.
Descrierea în detaliu a funcționalității hardware (ce module, componente, senzori, etc. ați folosit, prin ce interfețe se leagă la microcontroller-ul vostru, specificații de comunicație, procesare, calcule de consum de energie și orice altceva considerați relevant).
Descrieți în detaliu ce pini ai ESP32-C6 sunt folosiți pentru fiecare componentă și de ce.
Orice altceva considerați că ar fi relevant pentru review (design log, imagini cu randări ale PCB-ului, așezarea componentelor în carcasă etc.).

Closed 2025-04-15.

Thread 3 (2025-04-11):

PCB

SebiBahrin, 2025-04-11:
1. Antena modulului ESP32 trebuie să fie amplasată spre exteriorul PCB-ului și PCB-ul trebuie să fie decupat sub antenă! Din cate am observat tie iti trece si un fir prin zona antenei, de aceea trebuie mai intai sa decupezi placuta (de la Board Shape), iar dupa decupare va trebui sa dai Unroute - Unroute ALL si sa re-rutezi pentru a fi ok.

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

2. Iti lipseste planul de masa pentru buttom. Nu uita, in cazul în care rutarea s-a realizat pe 2 layere trebuie ca și planul de masă să fie realizat astfel.

3. Test pad-urile nu sunt marcate cu numele semnalelor pe care le poartă

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

4.Unele denumiri se suprapun cu rutele facute, muta denumirile imprejur pentru a fi clar de citit si a nu exista posibile ulterioare probleme cand placuta este realizata in viata reala.Ai grija totusi sa nu pui numele prea departate de componente, pentru a nu crea confuzii.

5. Nu uita sa rezolvi aceste 4 erori legate de copper width:

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

Closed 2025-04-15.

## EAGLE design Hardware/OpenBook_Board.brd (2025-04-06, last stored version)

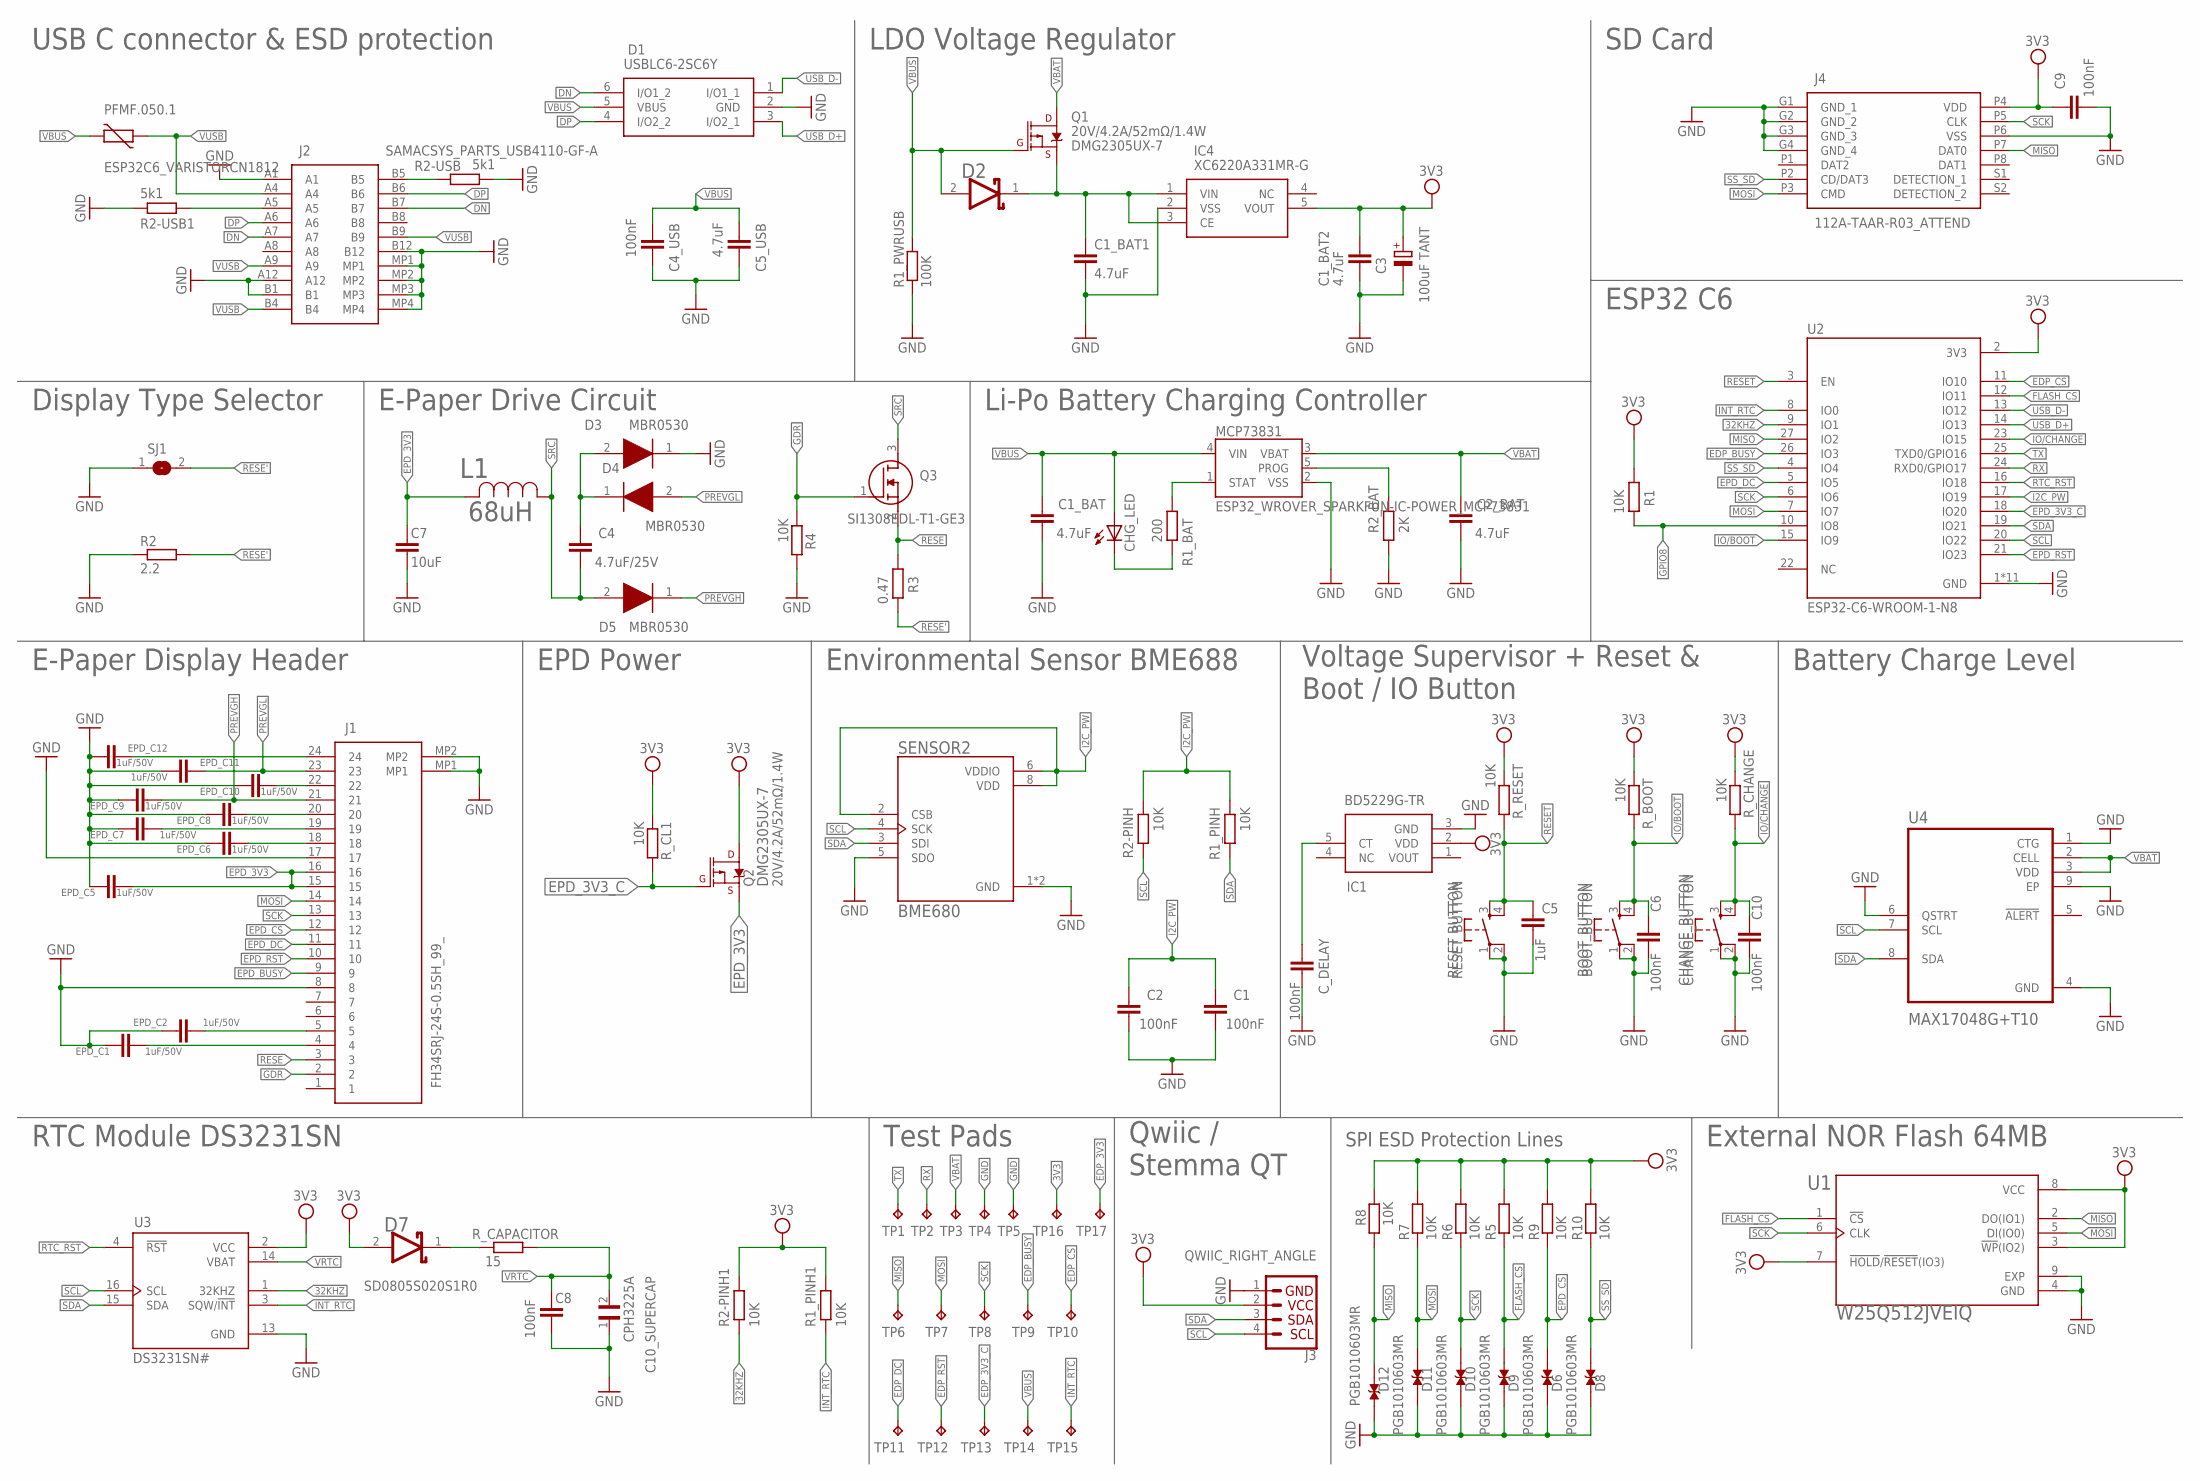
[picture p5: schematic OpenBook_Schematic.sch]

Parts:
BOOT_BUTTON: BOOT_BUTTON; MYBUTTON
C1, C2, C4_USB, C6, C8, C9, C10: 100nF; EAGLE-LTSPICE_C0402
C1_BAT, C1_BAT1, C1_BAT2, C2_BAT, C5_USB: 4.7uF; EAGLE-LTSPICE_C0402
C3: 100uF TANT; RCL_CT3528
C4: 4.7uF/25V; EAGLE-LTSPICE_C0402
C5: 1uF; EAGLE-LTSPICE_C0402
C7: 10uF; EAGLE-LTSPICE_C0402
C10_SUPERCAP: CPH3225A; CAPCP3225X100N
CHANGE_BUTTON: CHANGE_BUTTON; MYBUTTON
CHG_LED: ADAFRUIT_LEDCHIP-LED0603; ADAFRUIT_CHIP-LED0603
C_DELAY: 100nF; EAGLE-LTSPICE_C0402
D1: USBLC6-2SC6Y; SOT95P280X145-6N
D2, D7: ESP32_WROVER_AVX---SD0805S020S1R0_AVX_SD0805S020S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; ESP32_WROVER_AVX---SD0805S020S1R0_AVX_SD0805S020S1R0_0
D3, D4, D5: MBR0530; SOD3716X135N
D6, D8, D9, D10, D11, D12: PGB1010603MR; DIOC1608X36N
EPD_C1, EPD_C2, EPD_C5, EPD_C6, EPD_C7, EPD_C8, EPD_C9, EPD_C10, EPD_C11, EPD_C12: 1uF/50V; EAGLE-LTSPICE_C0402
IC1: BD5229G-TR; SOT95P280X120-5N
IC4: XC6220A331MR-G; SOT95P280X120-5N
J1: FH34SRJ-24S-0.5SH_99_; FH34SRJ24S05SH99
J2: SAMACSYS_PARTS_USB4110-GF-A; SAMACSYS_PARTS_USB4110GFA
J3: QWIIC_RIGHT_ANGLE; JST04_1MM_RA
J4: 112A-TAAR-R03_ATTEND; 112ATAARR03ATTEND
L1: 68uH; IND_4828-WE-TPC_WRE
MCP73831: ESP32_WROVER_SPARKFUN-IC-POWER_MCP73831; ESP32_WROVER_SPARKFUN-IC-POWER_SOT23-5
PFMF.050.1: ESP32C6_VARISTORCN1812; ESP32C6_VARISTOR_CT/CN1812
Q1, Q2: 20V/4.2A/52mΩ/1.4W; ESP32_WROVER_SPARKFUN-DISCRETESEMI_SOT23-3
Q3: SI1308EDL-T1-GE3; SOT65P210X110-3N
R1, R1_PINH, R1_PINH1, R2-PINH, R2-PINH1, R4, R5, R6, R7, R8, R9, R10: 10K; ESP32_WROVER_EAGLE-LTSPICE_R0402
R1_BAT: 200; ESP32_WROVER_EAGLE-LTSPICE_R0402
R1_PWRUSB: 100K; ESP32_WROVER_EAGLE-LTSPICE_R0402
R2: 2.2; ESP32_WROVER_EAGLE-LTSPICE_R0402
R2-USB, R2-USB1: 5k1; ESP32_WROVER_EAGLE-LTSPICE_R0402
R2_BAT: 2K; ESP32_WROVER_EAGLE-LTSPICE_R0402
R3: 0.47; ESP32_WROVER_EAGLE-LTSPICE_R0402
RESET_BUTTON: RESET BUTTON; MYBUTTON
R_BOOT: 10K; ESP32_WROVER_EAGLE-LTSPICE_R0402
R_CAPACITOR: 15; ESP32_WROVER_EAGLE-LTSPICE_R0402
R_CHANGE: 10K; ESP32_WROVER_EAGLE-LTSPICE_R0402
R_CL1: 10K; ESP32_WROVER_EAGLE-LTSPICE_R0402
R_RESET: 10K; ESP32_WROVER_EAGLE-LTSPICE_R0402
SENSOR2: BME680; ESP32_WROVER_BME680_PSON80P300X300X100-8N
SJ1: SJ
TP1, TP2, TP3, TP4, TP5, TP6, TP7, TP8, TP9, TP10, TP11, TP12, TP13, TP14, TP15, TP16, TP17: TPTP20R; TP20R
U1: W25Q512JVEIQ; SON127P600X800X80-9N
U2: ESP32-C6-WROOM-1-N8; XCVR_ESP32-C6-WROOM-1-N8
U3: DS3231SN#; SOIC127P1032X265-16N
U4: MAX17048G+T10; SON50P200X200X80-9N

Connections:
3V3: C1_BAT2.1, C3.+, C9.1, D7.2 (ANODE), IC1.2 (VDD), IC4.5 (VOUT), J3.2, J4.P4 (VDD), Q2.3 (D), R1.1, R1_PINH1.2, R2-PINH1.2, R5.2, R6.2, R7.2, R8.2, R9.2, R10.2, R_BOOT.1, R_CHANGE.1, R_CL1.1, R_RESET.1, TP16.TP, U1.3 (!WP!(IO2)), U1.7 (!HOLD!/!RESET!(IO3)), U1.8 (VCC), U2.2 (3V3), U3.2 (VCC)
32KHZ: R2-PINH1.1, U2.9 (IO1), U3.1 (32KHZ)
DN: D1.6 (I/O1_2), J2.A7, J2.B7
DP: D1.4 (I/O2_2), J2.A6, J2.B6
EDP_3V3: TP17.TP
EDP_3V3_C: TP13.TP
EDP_BUSY: TP9.TP, U2.26 (IO3)
EDP_CS: TP10.TP, U2.11 (IO10)
EDP_DC: TP11.TP
EDP_RST: TP12.TP
EPD_3V3: C7.1, EPD_C5.1, J1.15, J1.16, L1.2, Q2.2 (S)
EPD_3V3_C: Q2.1 (G), R_CL1.2, U2.18 (IO20)
EPD_BUSY: J1.9
EPD_CS: D6.2, J1.12, R9.1
EPD_DC: J1.11, U2.5 (IO5)
EPD_RST: J1.10, U2.21 (IO23)
FLASH_CS: D9.2, R5.1, U1.1 (!CS), U2.12 (IO11)
GDR: J1.2, Q3.1 (G), R4.1
GND: BOOT_BUTTON.1, BOOT_BUTTON.2, C1.2, C1_BAT.2, C1_BAT1.2, C1_BAT2.2, C2.2, C2_BAT.2, C3.-, C4_USB.2, C5.2, C5_USB.2, C6.2, C7.2, C8.2, C9.2, C10.2, C10_SUPERCAP.1, CHANGE_BUTTON.1, CHANGE_BUTTON.2, C_DELAY.2, D1.2 (GND), D3.1 (K), D6.1, D8.1, D9.1, D10.1, D11.1, D12.1, EPD_C1.2, EPD_C2.2, EPD_C5.2, EPD_C6.2, EPD_C7.2, EPD_C8.2, EPD_C9.2, EPD_C10.2, EPD_C11.2, EPD_C12.2, IC1.3 (GND), IC4.2 (VSS), J1.8, J1.17, J1.MP1, J1.MP2, J2.A1, J2.A12, J2.B1, J2.B12, J2.MP1, J2.MP2, J2.MP3, J2.MP4, J3.1, J4.G1 (GND_1), J4.G2 (GND_2), J4.G3 (GND_3), J4.G4 (GND_4), J4.P6 (VSS), MCP73831.2 (VSS), R1_PWRUSB.1, R2.1, R2-USB.2, R2-USB1.1, R2_BAT.1, R4.2, RESET_BUTTON.1, RESET_BUTTON.2, SENSOR2.1 (GND), SENSOR2.5 (SDO), SENSOR2.7 (GND), SJ1.1, TP4.TP, TP5.TP, U1.4 (GND), U1.9 (EXP), U2.1 (GND), U2.28 (GND), U2.29_1 (GND), U2.29_2 (GND), U2.29_3 (GND), U2.29_4 (GND), U2.29_5 (GND), U2.29_6 (GND), U2.29_7 (GND), U2.29_8 (GND), U2.29_9 (GND), U3.13 (GND), U4.1 (CTG), U4.4 (GND), U4.6 (QSTRT), U4.9 (EP)
GPIO8: R1.2, U2.10 (IO8)
I2C_PW: C1.1, C2.1, R1_PINH.1, R2-PINH.1, SENSOR2.2 (CSB), SENSOR2.6 (VDDIO), SENSOR2.8 (VDD), U2.17 (IO19)
INT_RTC: R1_PINH1.1, TP15.TP, U2.8 (IO0), U3.3 (SQW/!INT)
IO/BOOT: BOOT_BUTTON.3, BOOT_BUTTON.4, C6.1, R_BOOT.2, U2.15 (IO9)
IO/CHANGE: C10.1, CHANGE_BUTTON.3, CHANGE_BUTTON.4, R_CHANGE.2, U2.23 (IO15)
MISO: D12.2, J4.P7 (DAT0), R8.1, TP6.TP, U1.2 (DO(IO1)), U2.27 (IO2)
MOSI: D11.2, J1.14, J4.P3 (CMD), R7.1, TP7.TP, U1.5 (DI(IO0)), U2.7 (IO7)
unnamed: J2.A5, R2-USB1.2
unnamed: C1_BAT1.1, D2.1 (CATHODE), IC4.1 (VIN), IC4.3 (CE), Q1.2 (S)
unnamed: MCP73831.1 (STAT), R1_BAT.1
unnamed: J2.B5, R2-USB.1
unnamed: CHG_LED.C, R1_BAT.2
unnamed: EPD_C12.1, J1.24
unnamed: MCP73831.5 (PROG), R2_BAT.2
unnamed: C4.1, D3.2 (A), D4.1 (K)
unnamed: C_DELAY.1, IC1.5 (CT)
unnamed: EPD_C10.1, J1.22
unnamed: EPD_C8.1, J1.20
unnamed: EPD_C7.1, J1.19
unnamed: EPD_C6.1, J1.18
unnamed: EPD_C2.1, J1.5
unnamed: EPD_C1.1, J1.4
unnamed: D7.1 (CATHODE), R_CAPACITOR.2
PREVGH: D5.1 (K), EPD_C9.1, J1.21
PREVGL: D4.2 (A), EPD_C11.1, J1.23
RESE: J1.3, Q3.2 (S), R3.1
RESE': R2.2, R3.2, SJ1.2
RESET: C5.1, RESET_BUTTON.3, RESET_BUTTON.4, R_RESET.2, U2.3 (EN)
RTC_RST: U2.16 (IO18), U3.4 (!RST)
RX: TP2.TP, U2.24 (RXD0/GPIO17)
SCK: D10.2, J1.13, J4.P5 (CLK), R6.1, TP8.TP, U1.6 (CLK), U2.6 (IO6)
SCL: J3.4, R2-PINH.2, SENSOR2.4 (SCK), U2.20 (IO22), U3.16 (SCL), U4.7 (SCL)
SDA: J3.3, R1_PINH.2, SENSOR2.3 (SDI), U2.19 (IO21), U3.15 (SDA), U4.8 (SDA)
SRC: C4.2, D5.2 (A), L1.1, Q3.3 (D)
SS_SD: D8.2, J4.P2 (CD/DAT3), R10.1, U2.4 (IO4)
TX: TP1.TP, U2.25 (TXD0/GPIO16)
USB_D+: D1.3 (I/O2_1), U2.14 (IO13)
USB_D-: D1.1 (I/O1_1), U2.13 (IO12)
VBAT: C2_BAT.1, MCP73831.3 (VBAT), Q1.3 (D), TP3.TP, U4.2 (CELL), U4.3 (VDD)
VBUS: C1_BAT.1, C4_USB.1, C5_USB.1, CHG_LED.A, D1.5 (VBUS), D2.2 (ANODE), MCP73831.4 (VIN), PFMF.050.1.2, Q1.1 (G), R1_PWRUSB.2, TP14.TP
VRTC: C8.1, C10_SUPERCAP.2, R_CAPACITOR.1, U3.14 (VBAT)
VUSB: J2.A4, J2.A9, J2.B4, J2.B9, PFMF.050.1.1

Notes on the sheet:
USB C connector & ESD protection
LDO Voltage Regulator
DMG2305UX-7
SD Card
Display Type Selector
E-Paper Drive Circuit
Li-Po Battery Charging Controller
ESP32 C6
E-Paper Display Header
EPD Power
Environmental Sensor BME688
Voltage Supervisor + Reset & Boot / IO Button
Battery Charge Level
RTC Module DS3231SN
SD0805S020S1R0
Test Pads
Qwiic / Stemma QT
SPI ESD Protection Lines
External NOR Flash 64MB

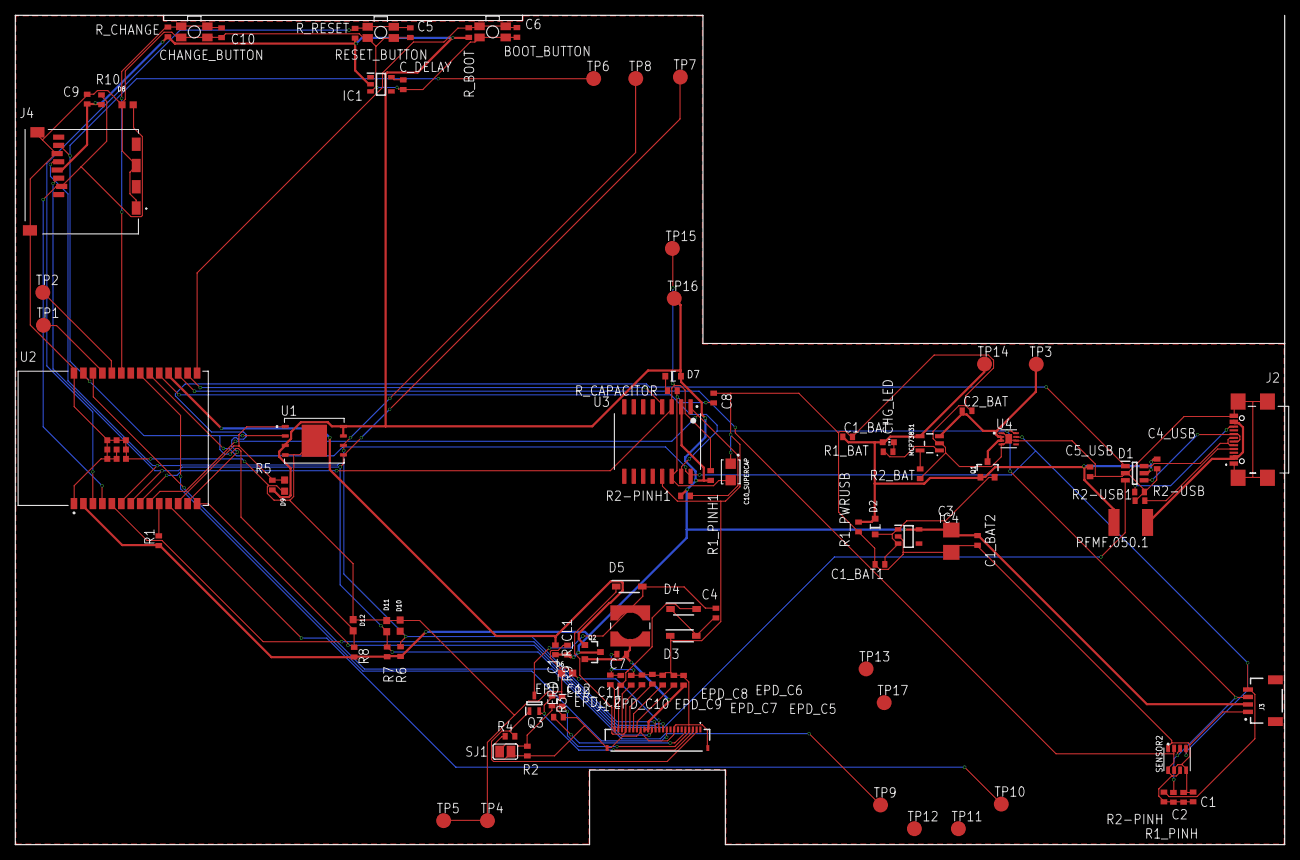
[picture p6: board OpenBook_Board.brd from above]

Board: 2 copper layers, 170.2 x 111.2 mm, 103 parts (0 on the bottom side), 56 nets.

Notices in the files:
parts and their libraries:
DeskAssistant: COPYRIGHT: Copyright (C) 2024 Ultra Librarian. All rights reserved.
